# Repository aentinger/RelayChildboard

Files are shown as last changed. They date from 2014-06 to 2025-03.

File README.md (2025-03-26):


💾 Relay Childboard
===================



# 📸 Image

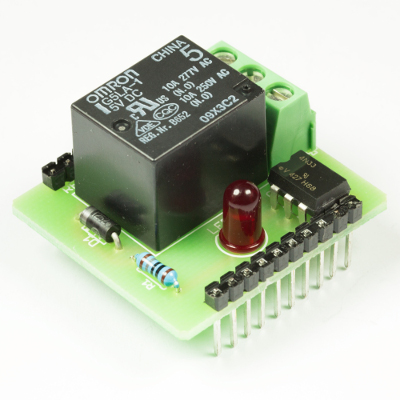
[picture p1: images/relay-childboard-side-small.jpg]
LXRobotics P6_3 Relay Childboard


# 📂 Description

The LXRobotics Relay Childboard allows to turn on/off a load via a relay. The switching status of the relay is visualized by a red status LED. High quality screw terminals ensure stable and durable connection. For a quick and easy start, an open source Arduino library with sample programs is available.

**Features**

* Control a single load via a relay
* Max current. 10 A
* Max. DC voltage: 24 V DC
* Max. AC voltage: 250 V AC
* Relay-Type: SPDT (Single Pole commutator)
* Red signal LED shows relay status (ON/OFF)
* Optocouplers insulate Arduino from Relay circuit
* High quality screw terminals
* Can be used with the Radioshield the Childboard Adaptershield
* Arduino Library with example programs is available on GitHub

# 🎥 [Video](images/childboard_relay_demo.mp4)

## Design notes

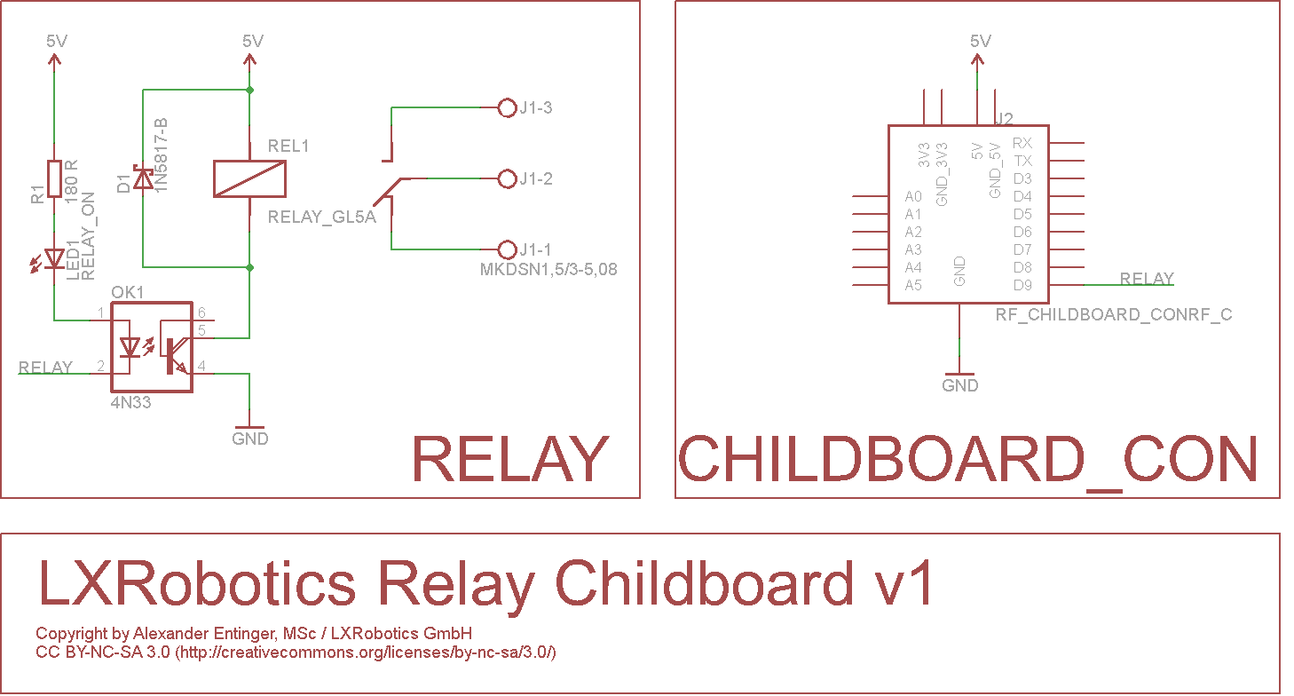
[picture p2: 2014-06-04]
hardware/lxr_childboard_relay_v1.png

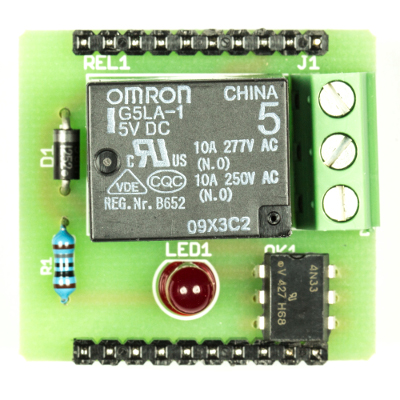
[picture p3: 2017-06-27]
images/relay-childboard-top-small.jpg

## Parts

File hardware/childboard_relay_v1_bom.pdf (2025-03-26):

Menge | Schaltplan | Bezeichnung | Farnell Bestell Nummer | Preis (1 Stück) | Gesamtpreis | Wird bestückt | Footprint | Säckchen | ESD
1 | REL1 | GL5A Leistungsrelais, 5 VDC, 250 V AC, 10 A, RCOIL = 70 R | 1455502 | € 1,43 | € 1,43 | | | S1
1 | OK1 | 4N33, Optokoppler mit Photo-Darlington, DIL06 | 1469601 | € 0,45 | € 0,45 | | | S2 | x
1 | D1 | 1N5817, Diode Shottkey, If=1A, Ur=20V | 1458990 | € 0,30 | € 0,30
1 | LED1 | LED Rot, 5 mm, Uf=1.9V, If=10 mA | 1660489 | € 0,35 | € 0,35
1 | R1 | Widerstand, 180 R, 0.25 W | 9341420 | € 0,02 | € 0,02
1 | J1 | Schraubklemme 3-Polig, MKDSN1.5/3-5.08 | 3041451 | € 1,42 | € 1,42 | | | S1
2 | J2 | RF Childboard Connector | 1022261 | € 0,36 | € 0,72
1 | Leitfähiger Schaumstoff | 1687855 | € | 2,40 | € | 2,40 | - | Bestellung von 1 Stück reicht für 50 Relay Childboards aus
| | | Summe | | € | 7,08

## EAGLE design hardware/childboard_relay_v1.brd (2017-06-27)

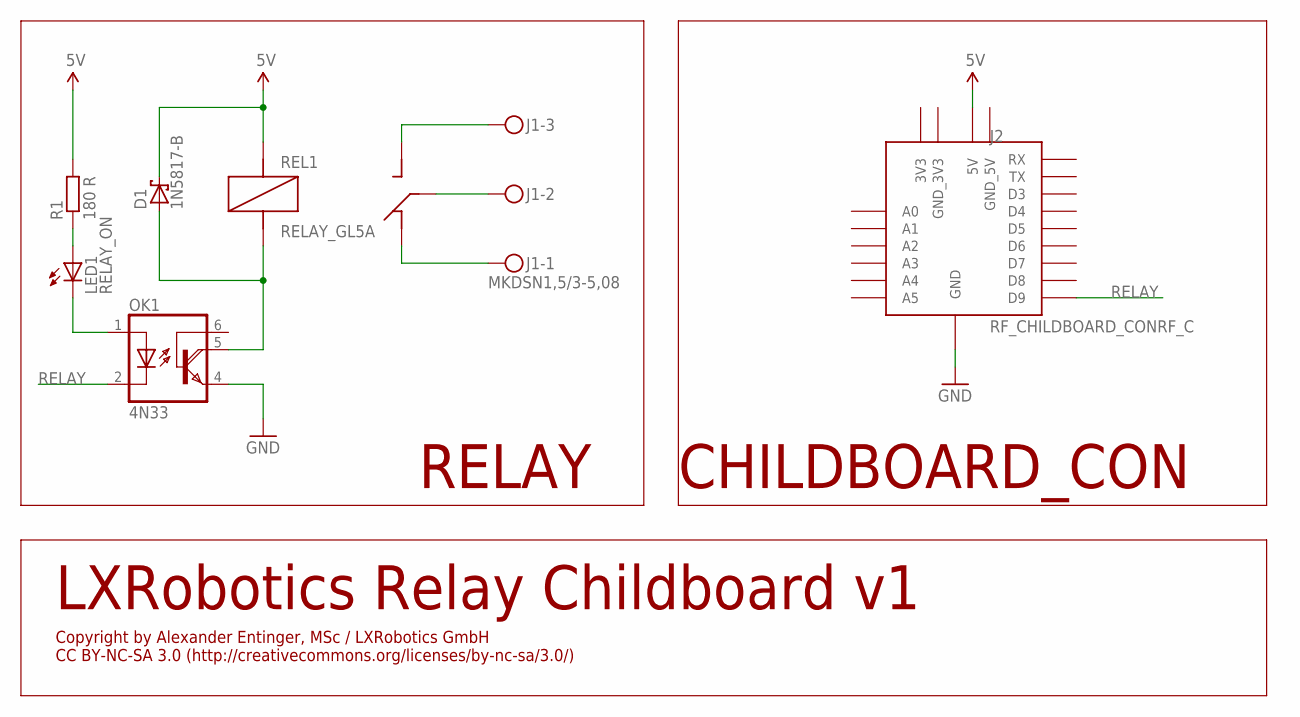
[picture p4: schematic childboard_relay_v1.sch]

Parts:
D1: 1N5817-B; DO41-7.6
J1: MKDSN1,5/3-5,08
J2: RF_CHILDBOARD_CONRF_C; RF_CHILDBOARD_CON
LED1: RELAY_ON; LED5MM
OK1: 4N33; DIL06
R1: 180 R; 0204/7
REL1: RELAY_GL5A

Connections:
5V: D1.C, J2.5V, R1.2, REL1.R2 (R2_COIL1)
GND: J2.GND_ (GND), OK1.4 (E)
unnamed: J1.2, REL1.R1 (R1_COMMON)
unnamed: J1.3, REL1.R3 (R3_SW)
unnamed: J1.1, REL1.R4 (R4_SW)
unnamed: LED1.K (C), OK1.1 (A)
unnamed: D1.A, OK1.5 (COL), REL1.R5 (R5_COIL2)
unnamed: LED1.A, R1.1
RELAY: J2.D9, OK1.2 (C)

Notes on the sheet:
RELAY
CHILDBOARD_CON
LXRobotics Relay Childboard v1
Copyright by Alexander Entinger, MSc / LXRobotics GmbH CC BY-NC-SA 3.0 (http://creativecommons.org/licenses/by-nc-sa/3.0/)

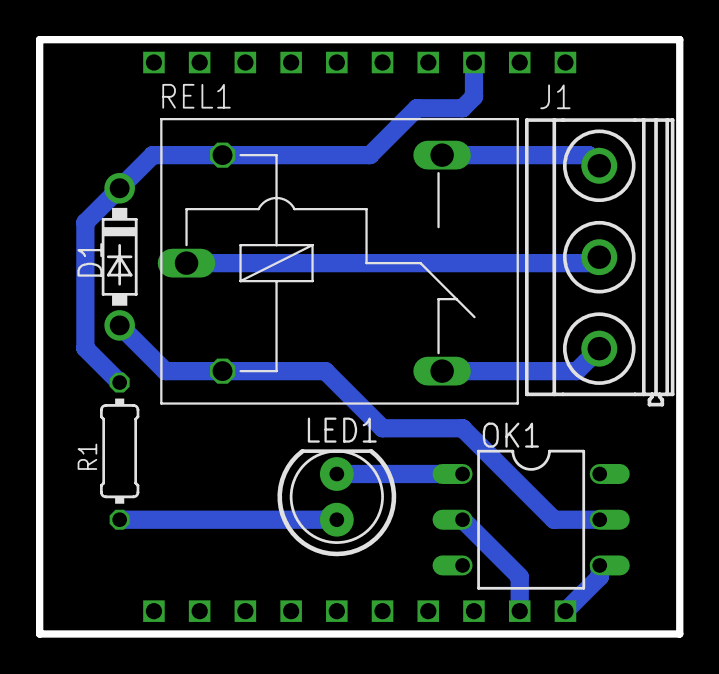
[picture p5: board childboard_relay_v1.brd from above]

Board: 2 copper layers, 35.6 x 33.0 mm, 7 parts (0 on the bottom side), 9 nets.

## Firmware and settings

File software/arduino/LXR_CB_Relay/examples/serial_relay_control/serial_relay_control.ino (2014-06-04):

/**
 * @author Alexander Entinger, MSc / LXRobotics
 * @brief this sketch demonstrates how to turn the LXRobotics Chilboard Relay on/off using a simple serial command
 * @file blink.ino
 */

#include "LXR_CB_Relay.h"

void setup() {
  LXR_CB_Relay::begin();
  Serial.begin(115200);
}

static char const ON = '1';
static char const OFF = '0';

void loop() {
  while(Serial.available() > 0) {
    char const received_byte = Serial.read();
      if(received_byte == ON) {
        LXR_CB_Relay::turn_on();
        Serial.println("ACK");
      } else if(received_byte == OFF) {
        LXR_CB_Relay::turn_off();
        Serial.println("ACK");
      } else {
        Serial.println("NOT ACK");
      }
  }
}

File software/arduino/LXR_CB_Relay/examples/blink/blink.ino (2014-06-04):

/**
 * @author Alexander Entinger, MSc / LXRobotics
 * @brief this sketch demonstrates how to use the LXRobotics Relay Childboard Library
 * @file blink.ino
 */

#include "LXR_CB_Relay.h"

void setup() {
  LXR_CB_Relay::begin();
}

void loop() {
  LXR_CB_Relay::turn_on();
  delay(1000);
  LXR_CB_Relay::turn_off();
  delay(1000);
}

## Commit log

2014-06-04 initial checkin of lxr chilboard relay repo data
2014-06-04 adding serial relay control example
2017-06-27 Adding hardware + images
    [childboard_relay_v1.brd, childboard_relay_v1.sch]
2025-03-26 Upload BOM.

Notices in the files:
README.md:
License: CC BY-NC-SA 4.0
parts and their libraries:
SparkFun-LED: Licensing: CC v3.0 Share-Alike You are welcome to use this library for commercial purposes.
